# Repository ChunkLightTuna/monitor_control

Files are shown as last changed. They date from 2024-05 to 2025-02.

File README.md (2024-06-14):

# Control Pad

Breaks out monitor controls into a desktop based keypad. Also runs a simple webserver on port 1602 to display text on
the screen from api requests.

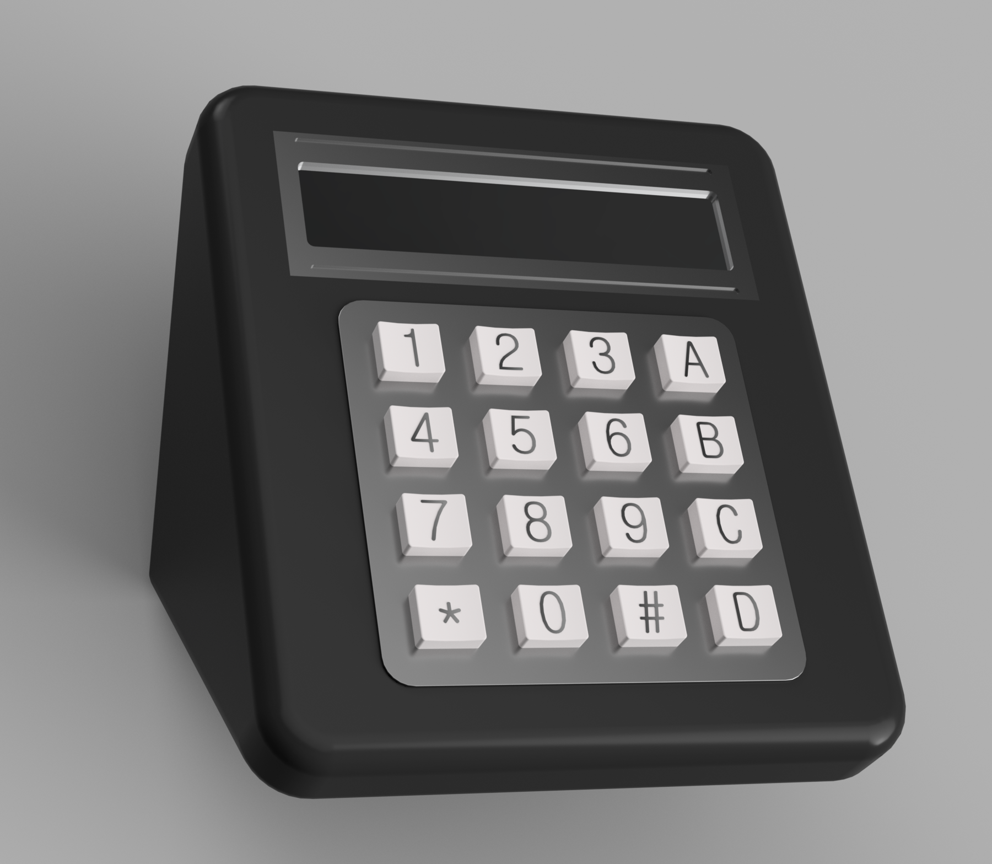
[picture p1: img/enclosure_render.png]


## Hardware

### Parts List

- [3D Printed Enclosure](3d_models/enclosure.3mf)
- Raspberry Pi Zero W
- [16x2 HD44780 LCD Display](https://www.adafruit.com/product/181)
- [4x4 Matrix Keypad](https://www.adafruit.com/product/3844)
- 10K Trimpot
- Female/Female Jumper Wires
- Micro USB Cable for power
- Mini HDMI Cable
- 4x M3x12 bolts
- 4x 10mm self adhesive rubber feet

### Assembly

See Adafruit's guides to wiring the
[display](https://learn.adafruit.com/drive-a-16x2-lcd-directly-with-a-raspberry-pi/wiring)
and
[keypad](https://learn.adafruit.com/matrix-keypad/python-circuitpython#python-computer-wiring-2998508).\
The pins on the lcd and display must be bent ~45° in order for them to fit inside the case.\
The protrusions in the 3d model sized for a ~18mm cylinder are to hold a chunk of steel to give it some extra weight.

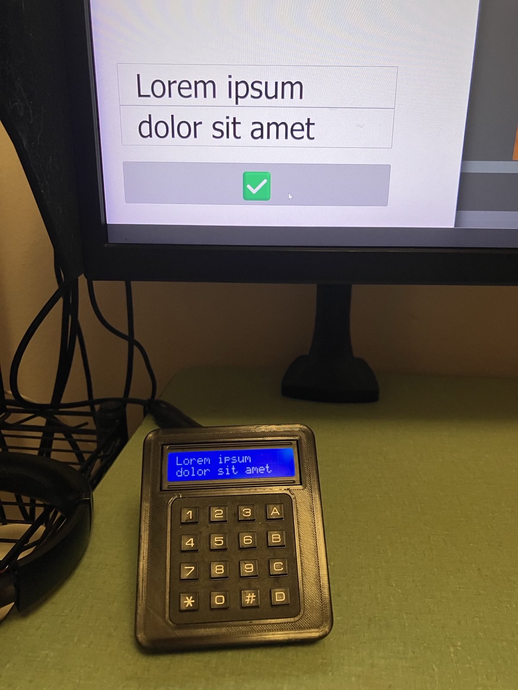
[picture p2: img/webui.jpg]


## Software

### Prerequisites

Controlling the monitor relies on the DDC/CI protocol.
This is done over the `/dev/i2c-2` interface which is disabled by default.
See [ddcutil's documentation](https://www.ddcutil.com/raspberry/) for details.
Enabling this requires adding a line to config.txt and a reboot.

```bash
echo "dtparam=i2c2_iknowwhatimdoing" | sudo tee -a /boot/firmware/config.txt
sudo reboot now
```

From a fresh Pi OS Lite image, ddcutil, pip and git are required.

```
sudo apt install ddcutil python3-pip git -y
```

### Installation

```bash
git clone https://github.com/ChunkLightTuna/monitor_control.git
cd monitor_control
python -m venv .venv
. .venv/bin/activate
pip install -r requirements.txt
```

### Config

Pin mappings are defined in [pinout.json](pinout.json). Note these are by GPIO/BCM number, not their physical position.
If you wire your pi up differently adjust the json accordingly.

Monitor IDs to be used under `displays` can be retrieved using the following `ddcutil` command:

```
ddcutil capabilities |  awk  '/Feature: 60/{f=1; next} f&&!/Feature/{print} /Feature/{f=0}'
```

Displaying weather forecast requires the [`OPEN_WEATHER_API_KEY`](https://home.openweathermap.org/users/sign_up), `LAT`
and `LONG` environment variables be set.
These may be defined in [monitor_control.service](monitor_control.sample.service). Port number may be modified from the
service file as well.

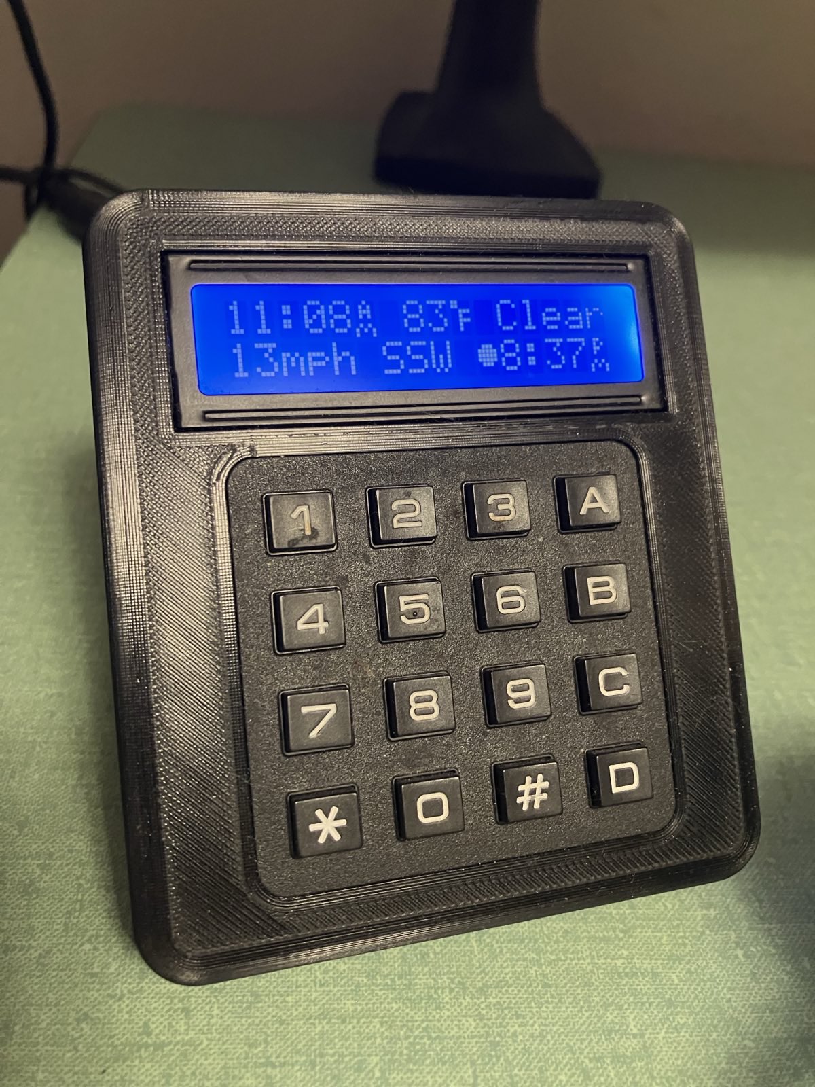
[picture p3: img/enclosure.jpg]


### Running
`uvicorn main:app --host 0.0.0.0` will run the app. 
From the initial screen press `2` or `8` to go to the Monitor Control menu.    
Pressing `A`, entering a number, and then `#` will set your display's audio level. \
`B` will do the same for brightness.
`C` will select the previous display, and `D` the next.

To persist as a systemd service, run the following: 
```bash
sed -e "s/\${DIR}/$(pwd | sed 's|/|\\\/|g')\/src/g" monitor_control.sample.service > monitor_control.service
systemctl enable --now "$(pwd)/monitor_control.service"
```

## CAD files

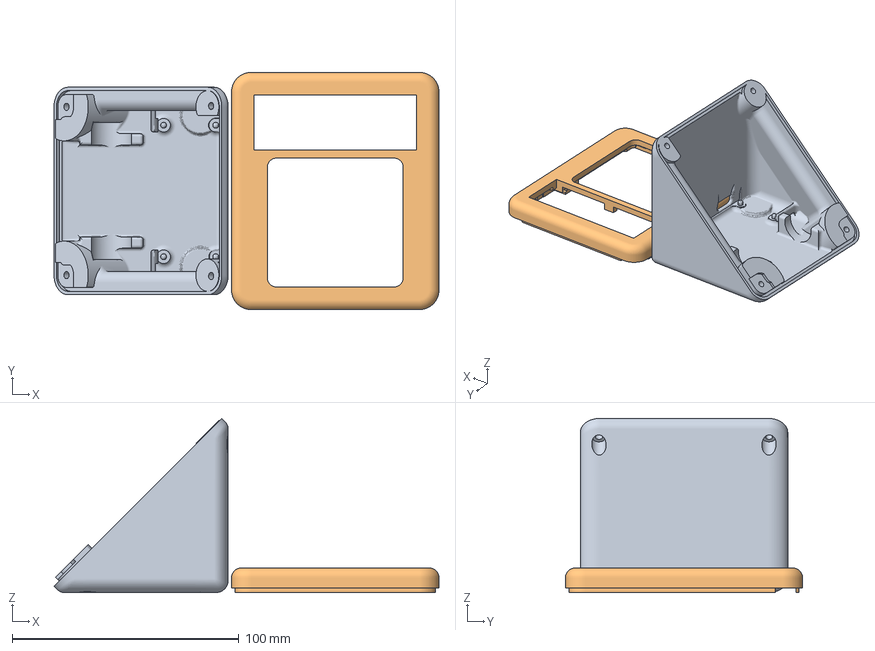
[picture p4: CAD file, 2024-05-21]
3d_models/enclosure.3mf
169.8 x 104.6 x 76.8 mm
bottom shell
top shell

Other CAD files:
3d_models/enclosure.stl

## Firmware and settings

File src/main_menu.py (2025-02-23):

import asyncio
import logging
from typing import Callable, List

from frame import Frame, Menu, MenuFrame
from kvm import KVM
from lcd import LCD, Msg
from pad import Keypad, SyntheticButton
from weather import Weather


class MainMenu(Menu):
    def __init__(self, keypad: Keypad):
        self.buttons: dict[str, SyntheticButton] = keypad.buttons
        self.kvm = KVM()
        self.lcd = LCD()

        self.cur = 0
        self.submenus: List[MenuFrame] = [
            Weather(self),
            MenuFrame(self, Msg('Main Menu').add_arrows())
        ]
        self.stack: List[Frame] = [self.submenus[0]]
        self.stack[0].activate()
        self.apply()

    async def run(self):
        await asyncio.gather(*[f() for f in [*self.stack, *self.submenus] if callable(f)])

    def prev_menu(self):
        self.submenus[self.cur].deactivate()
        self.cur = (self.cur - 1) % len(self.submenus)
        self.apply(self.submenus[self.cur])
        self.submenus[self.cur].activate()

    def next_menu(self):
        self.submenus[self.cur].deactivate()
        self.cur = (self.cur + 1) % len(self.submenus)
        self.apply(self.submenus[self.cur])
        self.submenus[self.cur].activate()

    def msg(self, msg: Msg | str) -> str:
        if isinstance(msg, str):
            msg = Msg(msg)

        self.lcd.msg(msg)
        return self.push(Frame(msg))

    def msg_ephemeral(self, msg: Msg | str, seconds=5):
        async def inner(m, s):
            key = self.msg(m)
            await asyncio.sleep(s)
            self.pop(key)

        asyncio.create_task(inner(msg, seconds))

    def numerical_input(self, msg: str, fun: Callable[[int], None], percent=True):
        queue = []

        # since self.msg at the bottom of this function adds to the stack, len() will refer to that element
        cur_stack = len(self.stack)

        for button in self.buttons.values():
            if button.label.isdigit():
                def inner(cur_label=button.label):  # default arg is required to wrap the button label in a closure
                    queue.append(cur_label)
                    stack_msg = self.stack[cur_stack].msg
                    num = ''.join(queue)
                    if percent:
                        num = f"{min(int(num), 100)}%"
                    stack_msg.line_two = f"""{num:>16}"""
                    self.lcd.msg(stack_msg)

                button.press = inner
            if button.label == '#':
                def commit():
                    fun(int(''.join(queue)))
                    self.pop()

                button.press = commit

        self.msg(msg)

    def apply(self, frame: Frame = None):
        if not frame:
            frame = self.stack[-1]

        for label, fun in frame.button_funs.items():
            self.buttons[label].press = fun
        self.lcd.msg(frame.msg)

    def push(self, frame: Frame) -> str:
        self.stack[-1].deactivate()
        frame.activate()
        self.stack.append(frame)
        return frame.key

    def pop(self, key: str = None):
        logging.info(f'pop {key=}')
        if len(self.stack) > 1:
            if key:
                idx = next((i for (i, s) in enumerate(self.stack) if key == s.key), None)
                if idx:
                    self.stack[idx].deactivate()
                    del self.stack[idx]
                    if idx != len(self.stack):
                        return  # don't need to refresh UI if pulling from middle of stack
            else:
                self.stack[-1].deactivate()
                self.stack.pop()

        self.stack[-1].activate()
        self.apply()

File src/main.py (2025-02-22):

import asyncio
import logging
from collections import deque
from contextlib import asynccontextmanager
from time import monotonic

from fastapi import FastAPI

import server
from lcd import Msg, Align
from main_menu import MainMenu
from pad import Keypad

logging.basicConfig(level=logging.INFO)
logging.info("""
    __  ___   ____     _   __    ____  ______   ____     ____           ______   ____     _   __  ______    ____    ____     __ 
   /  |/  /  / __ \   / | / /   /  _/ /_  __/  / __ \   / __ \         / ____/  / __ \   / | / / /_  __/   / __ \  / __ \   / / 
  / /|_/ /  / / / /  /  |/ /    / /    / /    / / / /  / /_/ /        / /      / / / /  /  |/ /   / /     / /_/ / / / / /  / /  
 / /  / /  / /_/ /  / /|  /   _/ /    / /    / /_/ /  / _, _/        / /___   / /_/ /  / /|  /   / /     / _, _/ / /_/ /  / /___
/_/  /_/   \____/  /_/ |_/   /___/   /_/     \____/  /_/ |_|         \____/   \____/  /_/ |_/   /_/     /_/ |_|  \____/  /_____/
                                                                                                                                
""")

keypad = Keypad()
menu = MainMenu(keypad)

MAX_INTERVAL = 30
RETRY_HISTORY = 3


# That is, stop after the 3rd failure in a 30 second moving window

def supervise(func, name=None, retry_history=RETRY_HISTORY, max_interval=MAX_INTERVAL):
    """Simple wrapper function that automatically tries to name tasks"""
    if name is None:
        if hasattr(func, '__name__'):  # raw func
            name = func.__name__
        elif hasattr(func, 'func'):  # partial
            name = func.func.__name__
    return asyncio.create_task(supervisor(func, retry_history, max_interval), name=name)


async def supervisor(func, retry_history=RETRY_HISTORY, max_interval=MAX_INTERVAL):
    """Takes a noargs function that creates a coroutine, and repeatedly tries
        to run it. It stops is if it thinks the coroutine is failing too often or
        too fast.
    """
    start_times = deque([float('-inf')], maxlen=retry_history)
    while True:
        start_times.append(monotonic())
        try:
            return await func()
        except asyncio.CancelledError:
            logging.exception(f'{func.__name__} cancelled.')
        except Exception as e:
            if min(start_times) > monotonic() - max_interval:
                raise e
            else:
                logging.exception(
                    f'{func.__name__} failed, will retry. Failed because:\n{str(e)}',
                    stack_info=True
                )


@asynccontextmanager
async def lifespan(_: FastAPI):
    menu.msg_ephemeral(Msg('Monitor', 'Control', align_two=Align.RIGHT))
    tasks = [
        supervise(keypad.run, name='Keypad'),
        supervise(menu.run, name='Menu')
    ]

    yield
    menu.msg(Msg('Shutting', 'Down', Align.CENTER, Align.CENTER))
    for task in tasks:
        task.cancel()


app = FastAPI(lifespan=lifespan, menu=menu)
app.include_router(server.router)

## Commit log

2022-08-28 fix not enough submitted error
    [server.py]
2024-05-18 avoid i2c pins
2024-05-21 Add ready to print 3d model
    [enclosure.3mf]
2024-06-09 I lack the self-discipline to effectively use loosely typed languages.
    [frame.py, main.py, main_menu.py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]
2024-06-14 def breaking things
    [enclosure.3mf]
2024-06-14 no debug and add stl files
    [bottom shell.stl, top shell.stl]
2024-06-14 add stl file
    [bottom shell.stl, enclosure.stl, top shell.stl]
